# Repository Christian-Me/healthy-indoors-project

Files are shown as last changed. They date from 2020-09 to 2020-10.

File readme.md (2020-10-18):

#  Healthy Indoors project (V0.0.2 ALPHA)

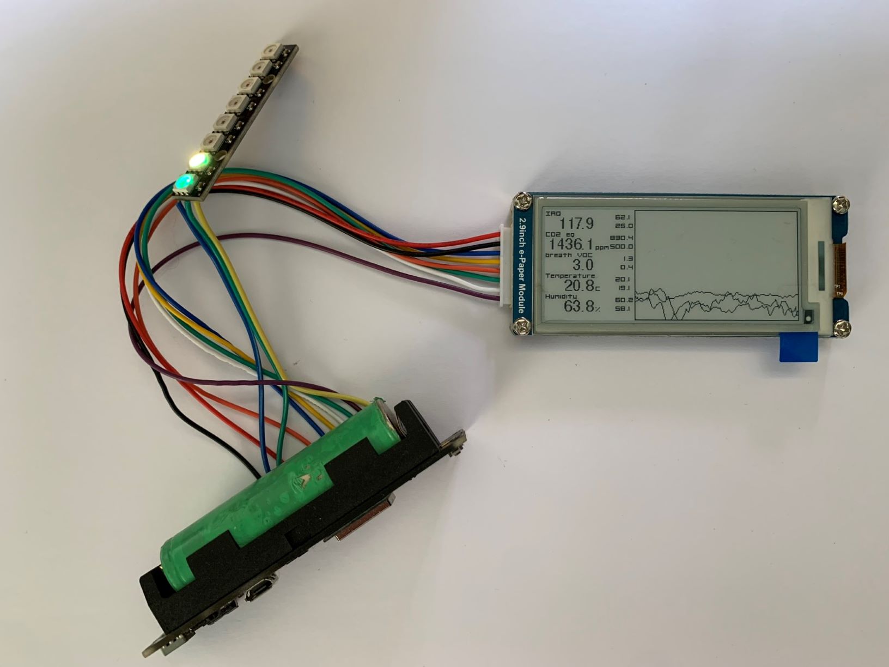
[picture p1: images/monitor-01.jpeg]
monitor node


## version 0.0.2

This version features a TFT monitor node (based on the e-paper version) giving more colorful charts

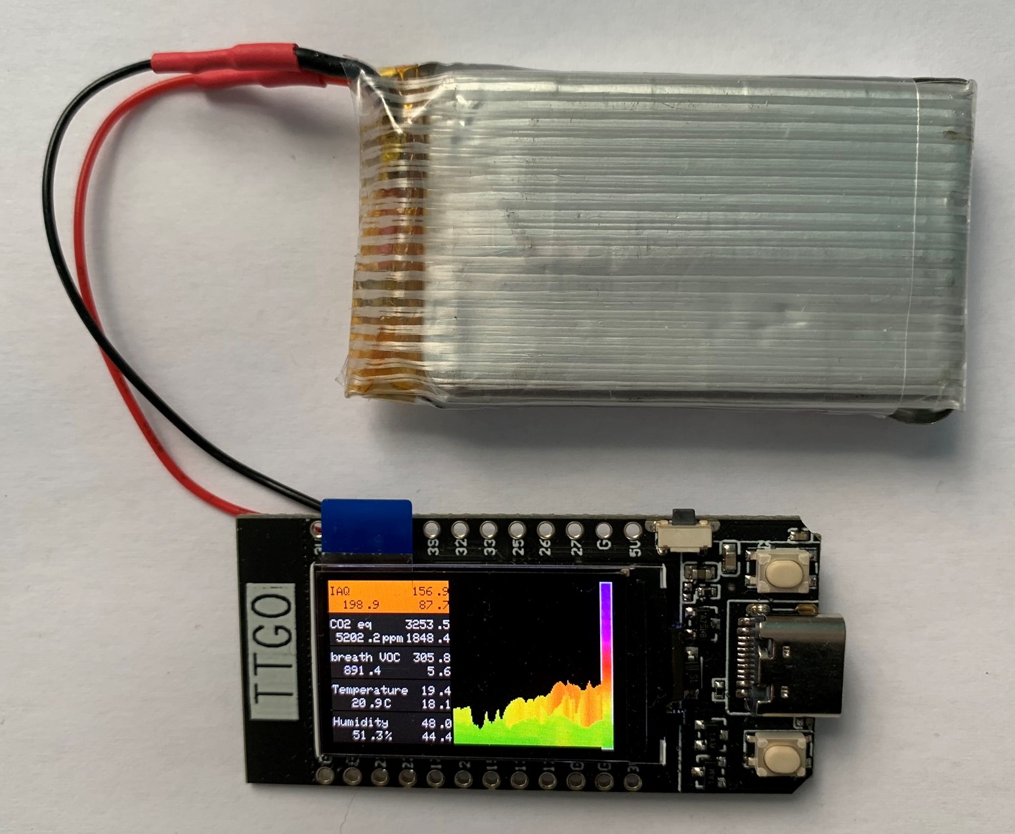
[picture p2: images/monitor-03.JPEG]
monitor node


even if TFT displays are not the best choice for battery powered nodes the small 1.14" TFT is nice (Note: The CO2 figures are CO2 equivalents by the VOC-Sensor - they are not really usable in the current setup)

[Perhaps you like to simulate thermodynamics in real time](./docs/energy2D.md)

open a window

[changes and improvements you find in the changelog](changelog.md)

[first case designs to print with any 3D-Printer](./3d-print/readme.md)

[general information about the software development environment](./docs/software.md)

<!-- START doctoc -->
<!-- END doctoc -->

## introduction

I started this project in September 2020 as a reaction of the global COVID-19 pandemic.

The need of an **as healthy as possible** indoor environment became necessary as it became obvious that [the virus is likely to be able to spread via aerosols](https://www.who.int/news-room/commentaries/detail/transmission-of-sars-cov-2-implications-for-infection-prevention-precautions) which could stay longer in the air and travel further inside rooms as droplets. 

Reading this study by [Risk assessment of aerosols loaded with virus based on CO2-concentration](https://blogs.tu-berlin.de/hri_sars-cov-2/wp-content/uploads/sites/154/2020/08/hartmann_kriegel_2020_en_v3.pdf) and many other publications and working in an open space office environment I was wondering if it is possible to develop indicators for the employees to be aware of the risk and take action. As humans are not good in sensing CO2 levels (or other gas concentrations affecting the air quality) sensors could be a possible way to help.

[Lately I was pointed to this Video](https://youtu.be/u2rNX2T2Hew?t=364). **This made me aware that other factors (humidity, temperature, particles) are important to factor in.** because they effect the *Virus Health (survivability)* and *Immune System health*. It could be important not only to concentrate on CO2 levels as an indicator to reduce the potential concentration COVID-19 (or other) Viruses but also on factors which maybe reduce the survivability of the virus and (perhaps most important) the immune system health of the occupants of a building. We could perhaps raise the risk of an infection if we do too much ventilation(?) and lower the temperature and weaken our immune system?

As we do not have to fit a [square container in a round canister](https://spacecenter.org/apollo-13-infographic-how-did-they-make-that-co2-scrubber/) when CO2 levels are rising. We can simply open the windows. In the beginning of the colder period and higher risk of infections of any kind the question is when, for how long. Second if the air exchange is sufficient. Mid of September Europe is seeing a second wave rising and as the outside temperatures will fall soon the need of an air exchange perhaps must be indicated due to the discomfort of cold air. Noisy street sounds might also prevent people from opening the windows.

Even without the current covid-19 crises the [health risks factors in indoor environments](https://www.euro.who.int/en/health-topics/environment-and-health/air-quality/publications/2015/the-school-environment-policies-and-current-status) should be addressed. Not all offices and nearly no schools have mechanical air ventilation systems (100% fresh air and no air circulation). 

["A new international day to celebrate clean air – and a sustainable recovery from COVID-19"](https://www.euro.who.int/en/health-topics/environment-and-health/air-quality/news/news/2020/9/a-new-international-day-to-celebrate-clean-air-and-a-sustainable-recove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)

## disclaimer

This project do not claim to prevent anybody form dangerous diseases or other harm. Stay distant, wear masks, perform any possible hygiene measures, think about possible ways to avoid long stays indoors, like work from home, remote schooling.

concept diagram

## the Idea

- develop a sensor network to detect accumulation of CO2 or other indicators like Humidity, Tempearture and Particle Concentration
- use multiple sensors to survey larger rooms, find "dead spots"
- Survey the effects of mechanical ventilation, air filters and other methods to improve air quality
- make the project open source that
   - others can participate
   - others can contribute
   - share data and experiences
- raise the awareness of risks in indoor environments
- learn how to improve the air quality and lower the risks with different methods
- test if "self-measured" values can help in communication air quality and perhaps behavior change

## the audience

- everybody who have to stay, study or work in indoor environments
- students who like to build sensor networks, code, analyse the data and perform experiments
- educators who like to teach various aspects form thermo dynamics, electronics, computer science, design, architecture, HVAC systems ... 
- students to get experiences in working on a project remotely using digital techniques like github to exchange ideas and knowlage across borders
- architects and engineers to design environments with better air quality in mind

## the project components

Nothing in this project is really new or innovative. Perhaps the local network idea is a little bit unusual as it does not need an access point as WiFi does. The goal is to establish an ad-hoc network with no setup. Simply place nodes in a room. All nodes in reach can talk to each other and exchange measurements. 

- **sensor nodes** sending environmental sensor readings onto the network
- **monitor nodes** Displaying sensor data on siple (RGB) LEDs, LED arrays, LCD, TFT or e-paper Displays. Monitor nodes can include sensors too.
- **bridge nodes** connecting the local sensor network to other networks like WiFi

### the micro-controller

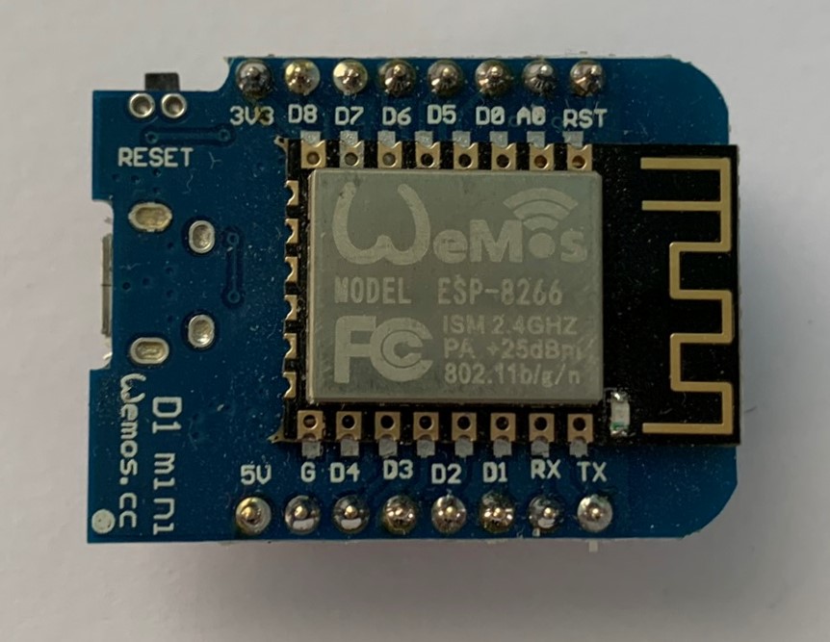
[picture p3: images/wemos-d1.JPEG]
wemos-d1


To start the ESP8266 (or ESP32) is used as it is a cheap and powerful micro-controller with 2.4GHz wireless transceiver build in. Other micro-controllers like Arduino (Atmel) or STM32 are possible but will need additional components for RF-Transmissions

### the network

Several networks and protocols can be used:

- **[esp-now](https://www.espressif.com/en/products/software/esp-now/overview)**: Access point / router free peer to peer ad-hoc network protocol for ESP8266/32 without additional components necessary (default protocol for this project)
- **NRF24L01**: 2.4GHz transceiver modules
- **[LoRa-Wan](https://de.wikipedia.org/wiki/Long_Range_Wide_Area_Network#Klasse_A)**: Long Range Wide Area Network - need of a gateway (public gateways are available). The monitor node can take the role of a gateway and create a local wireless network (to be investigated) and act as a bridge node too.
- **Wifi**: access point is necessary. An ESP8266/32 monitor node can take toe role of an software-AP
- **Bluetooth LE**: Simple data broadcasts over BLE should be possible (ESP32 only)

As esp-now runs natively on ESP8266 or ESP32 it seams like the ideal network protocol to start. The bridge node can connect esp-now to wifi or other networks and protocols

### sensor node

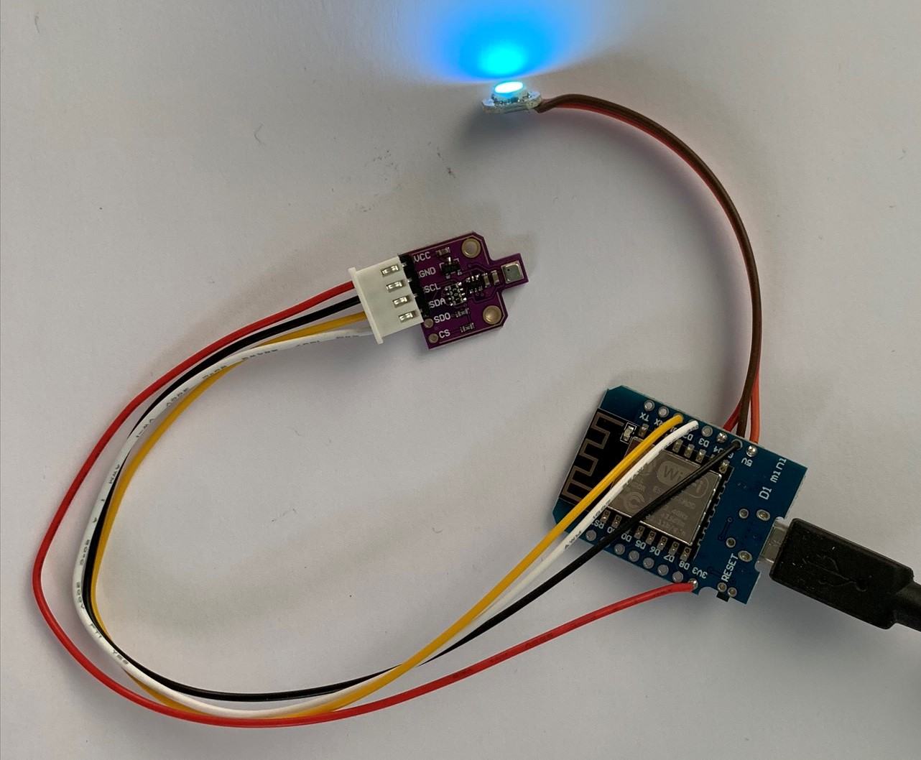
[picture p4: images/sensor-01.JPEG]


The simplest sensor node reads a connected gas sensor and broadcast its readings onto the network.

A Sensor node can also includes a monitor function to display its own sensor reading or if in a broadcast configuration readings of the other sensors too.

some interesting gas sensors (CO2 and VOC)

- **BME680** is an sensor by [Bosch Sensortec](https://www.bosch-sensortec.com/products/environmental-sensors/gas-sensors-bme680/) especially for indoor air quality measurements. Instead of measuring CO2 levels it measures volatile organic compounds (VOC). Not only harmful substances like formaldehyde, lacquers and others but also substances exhaled by humans.

  [interesting video about sensing VOC instead of CO2](https://www.youtube.com/watch?time_continue=1831&v=1niOmSsF-tk&feature=emb_logo)

  all tests in the current version of the project are done with three BME680
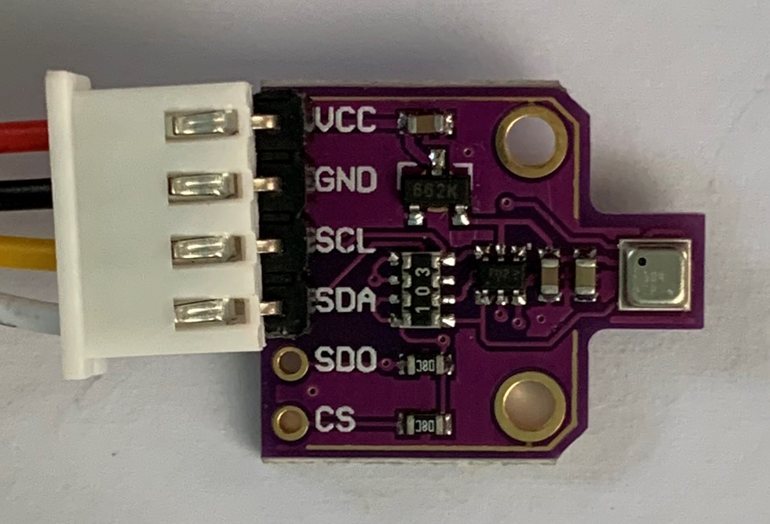
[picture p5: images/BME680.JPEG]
BME680

- **Senseair S8** promising infrared CO2 sensor from [Senseair](https://senseair.com/products/size-counts/s8-residential/) 400 to 2.000 ppm. (currently on delivery)

- **MH-Z19B** Chinese CO2 infrared Sensor from [Winsen-Sensors](https://www.winsen-sensor.com/sensors/co2-sensor/mh-z19b.html) 0 to 2.000 ppm.

- **CCS811** VOC sensor from [Sciosense](https://www.sciosense.com/products/environmental-sensors/ccs811-gas-sensor-solution/) seems interesting for battery operation as the sensor has a mcu integrated for VOC and eCO2 calculations providing a wake from deep sleep signal on programmable threshold alarm. **This sensor does not have a temperature and humidity sensor included! For more precise measurements a BME280, BME680 or similar should be included.**

### monitor nodes

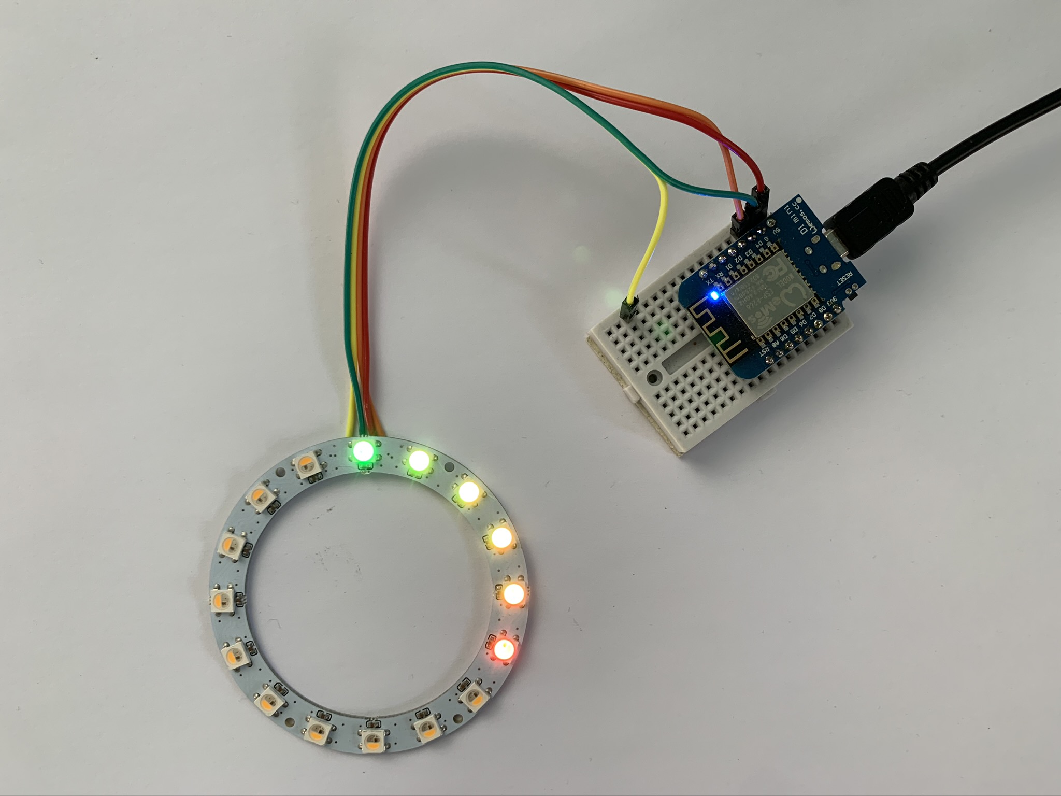
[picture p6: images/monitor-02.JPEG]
rgb-monitor


one or more monitor nodes can join the sensor network to display the air quality. Form a simple LED to RGB led strips, LCD, TFT, OLED or e-paper displays up to an alarm horn.

- A e-paper version is shown on top of the file. e-paper displays are attractive as they are easy to read and keep their contend during deep sleep.

- addressable RGB(W) strips or rings can display the sensor readings in a thermometer or gauge style. A RGB LED can be connected to every sensor node. Addressable RGB chips are preferred as they do not need further components like resistors and keep their state even if the mpu goes into deep sleep to save battery power.

- Small TFT or OLED displays are included in many ESP8266/32 boards. The M5Stack modules come with a TFT display and a attractive case and small LiPo battery

- ESP32 powered user programmable smart watches are available.

- other Monitor solutions can be implemented via bridge nodes

### bridge node

To connect the peer to peer network bridge nodes can join the network. A limitation of esp-now currently is that it does not coexists with WiFi at the same time. Currently that problem is solved by a *esp-now to serial* bridge. It could be solved by switching between esp-now and Wifi with the problem of missing data when switched to the other network.

- *serial2http bridge* The mcu provides a web server for displaying the data on mobile phones or desktop browsers

- *serial2mqtt bridge* (serial2homie) The mcu publishes the sensor data to a MQTT broker. As MQTT does not depend on a special data structure the [homie convention](https://homieiot.github.io/) is used to provide a structure how the sensors announce their services and data.

  Live data of my 3 BME680 are published on **mqtt://broker.hivemq.com:1833** topic: **healthy-indoors-project/#**

- other bridge nodes can be implemented like *serial2thingspeak* or *serial2blynk*

### data analyze

Using a **bridge node** and the mqtt protocoll the sensor data can by analyzed or visualized. The default tool should be [Node-RED](https://nodered.org)

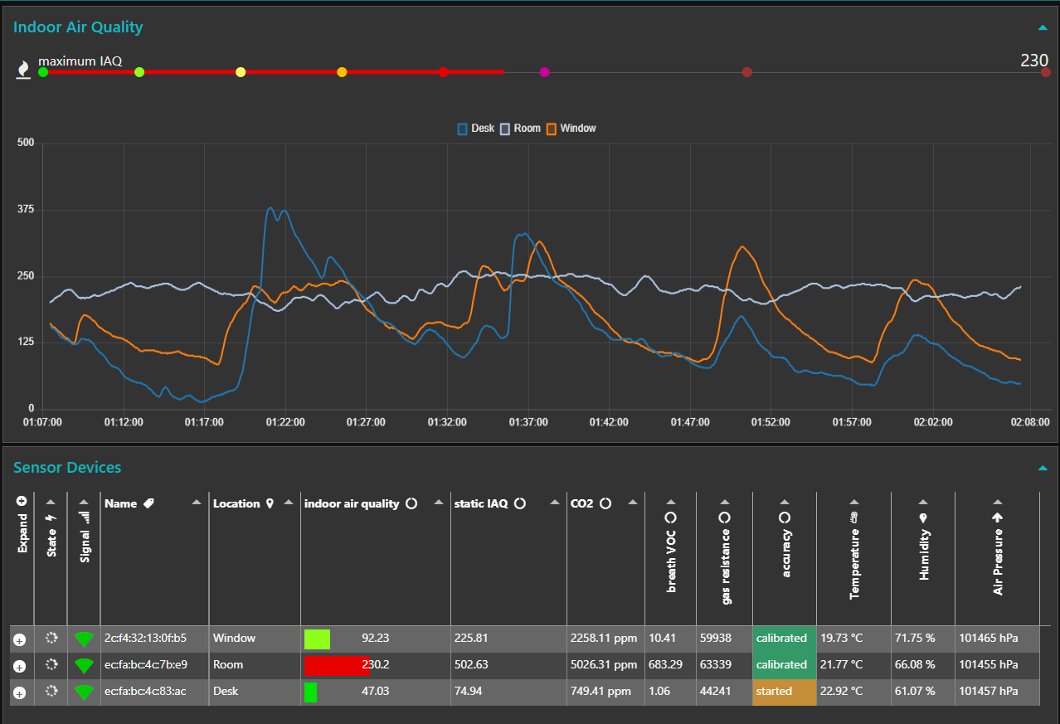
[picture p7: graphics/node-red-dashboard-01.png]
Node-RED dashboard


## project costs

All components are selected with a price point in mind that everybody can participate. Depending where (China or local) you buy the cost can be quite different. Local delivery can be 2-3x higher than orders form China including shipping. (detailed information on components and where to buy could be found in the near future)

- sensor node (8€-25€ BME680)
- monitor node (6€-20€ TFT / 18-30€ e-paper)
- bridge node (4-8€ 2x Wemos D1 mini)

## status of the project

The project is in a **proof of concept** stage. The following questions should be answered to progress:

- is the concept feasible and useful?
- how to interprete the the sensor data?
- how can the project implement in real world environments?
- how to communicate about air quality?

The next steps are

- design and 3D-Print cases for the nodes to take them out into the "real world"
- test nodes in office environments
- test nodes in classrooms
- develop battery powered nodes with suitable battery life
- develop a database solution and data analyze
- detect "window open" state by using window sensors or perhaps the build in temperature readings of most sensors could be used
- address security risks like encryption, authentication
- pairing functionality between nodes for multi room use

## participation and contributions

**The project is seeking for any participation as this is it's main goal!**

- test implementations
- school projects
- scientific advice
- help in any kinds of hardware development. Perhaps producing custom PCBs
- help in software development
- help in addressing security concerns
- any Ideas
- support of any kind
- [...]

## conclusion

As mentioned above this project can only be a small part in fighting against the covid-19 pandemic. Other measures might be more effective but I have a strong believe that there isn't a single solution but many small actions can help flattening the second curve as it is already rolling in.

Feel free to contact me (cmeinert@gmx.net) or use a github issue to enable others to participate.

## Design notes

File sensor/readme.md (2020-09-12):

BME680

Latest Drivers: https://github.com/BoschSensortec/BSEC-Arduino-library

For use with an ESP8266 or ESP32 oyu might have to edit eagle.app.v6.common.ld.h

C:\Users\<username>\.platformio\packages\framework-arduinoespressif8266\tools\sdk\ld

see: https://github.com/BoschSensortec/BSEC-Arduino-library#4-additional-core-specific-modifications

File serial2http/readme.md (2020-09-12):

bridge2http

***************************************
currently NOT working 
any help appreciated
use espnow2serial instead for now
***************************************

receives data form the sensor nodes and makes them accessible via web browser

Based on: https://randomnerdtutorials.com/esp32-esp-now-wi-fi-web-server/
Discussion: https://rntlab.com/question/esp-now-gateway-wifi_mode_sta-with-a-wifi-router/

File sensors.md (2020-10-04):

[BME680 by BOSCH Sensortec](https://www.bosch-sensortec.com/products/environmental-sensors/gas-sensors-bme680/)
[ccs811 by Sciosense](https://www.sciosense.com/products/environmental-sensors/ccs811-gas-sensor-solution/)
[MH-Z19B by Winsen-Sensors](https://www.winsen-sensor.com/sensors/co2-sensor/mh-z19b.html)

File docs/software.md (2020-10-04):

# how to build your own firmware

## project organization 

The project currently knows tree different nodes

- **sensor nodes** containing one or many sensors
- **monitor nodes** nodes to process and display the data
- **bridges** nodes to act as bridges between network protocol and typologies

The functionality of a node is not limited. So for example a monitor node can carry a sensor too or a bridge a display. Even an all in one node is possible. Every node project is a own folder in this project. Ideally it only carries the code necessary for this special node and uses the provided libraries for all the other stuff. 
The build process is controlled by build environments and build flags so functions can be switched on or off by simply commenting or un commenting lines.

## Integrated Development Environment IDE

This project use VSCode together with platform.io as development environment. Instead of using the arduino IDE vs code brings a lot of advantages:

- **One editor for many languages:** The Editor can be used not only for programming micro controller in C/C++ the same environment can be used for Python, JavaScript, PHP, HTML, CSS and many other languages
- **Code Completion** VSCode makes suggestions when you type. This is based not only on dictionaries but also on language structures
- **Linter:** VSCode runs syntax checks and even a compiler in background as you type. So may mistakes or typos are quickly marked before compiling.
- **git and github integration:** Seamless integration of many git and github tools for code versioning & collaboration via github
- **Professional organization:** VSCode brings a professional code organization with standardized file types and structures.
- and many many more features through thousands of extensions.

As a compile / make / build / upload and debug extension platform.io is used. It integrates many hundred of different micro controller, frameworks and boards. This awesome project helps to setup and maintain your build environment together with a in circuit debugger.

Many project like this are using the arduino IDE. This IDE is great as it tricks the newcomer into coding for micro controller in C/C++ by providing a simple to use IDE and simply not telling the user that he is about to learn C/C++. But the Arduino IDE has it's limitations. The code can be interchanged between vscode and Arduino IDE but many adaptations and reorganization has to be done.

The IDE should not be mixed with the framework. A framework organize all the features of different micro controllers in an standard way to do the heavy hardware related lifting. The arduino framework is beside espressive IDF the most popular framework. Many tools and libraries run with the arduiono framework.

## the libraries

The project contains three libraries types providing APIs for certain tasks

- **sensors** these Libraries start with an "s_" like **s_bme680** and interface between the sensor hardware or library and the project
- **communication** these libraries start with "c_" like **c_espnow** interface between the network and the project
- **monitor** these libraries start with "m_" like **m_epaper** to display sensor data

Beside that some other libs exists

- **chart.h** displaying charts on matrix displays
- **color.h** color conversion and calculations
- **ui.h** simple user interface
- **untils.h** misc utilities functions

The following standard libraries are currently used and can be installed by the platform.io library manager (if not automatically installed)

- **Button2** handle button presses, de-bouncing and long- or multiple button presses.
- **GxEPD2** including **Adafruit GFX** and **Adafruit BusIO** to interface with e-paper displays (could perhaps streamlined together with TFT_eSPI)
- **TFT_eSPI** to interface with TFT displays, touch screens and perhaps e-paper displays
- **Adafruit NoPixel** driving addressable RGB and RGBW LEDs

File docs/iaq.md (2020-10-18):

# the Indoor Air Quality index

*need to be revised. These are only data found in the internet*

## introduction

the IAQ is a artificial index defined by the EPA [(United States Environmental Protection Agency)](https://www.epa.gov/indoor-air-quality-iaq). It defines the range from 0-500 in six different categories. The advantage of the IAQ seams to be that many different indices can be mapped into the IAQ Index.

In these project the maximum IAQ is used as an indicator of the Air quality of the room. If necessary the values of different sensors can be weighted to reflect the significance of the sensor type and the relevance of the parameter in the future.

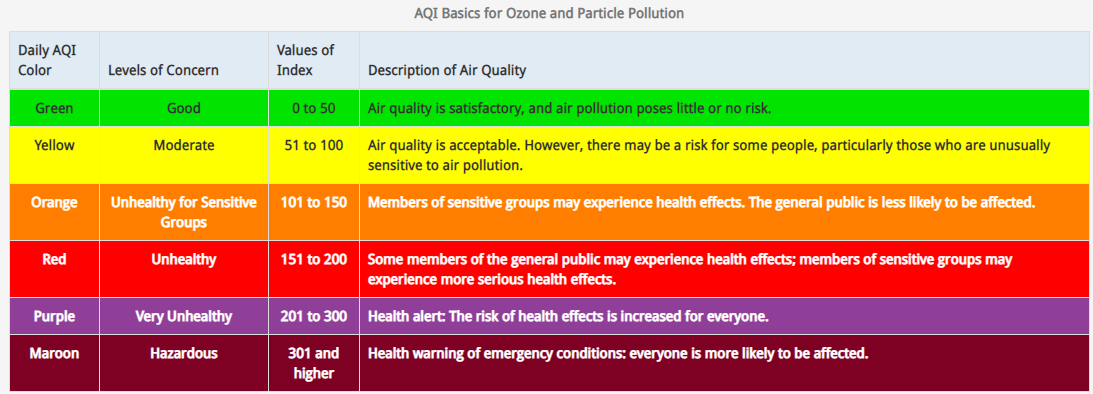
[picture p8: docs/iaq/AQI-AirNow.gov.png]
IAQ overview


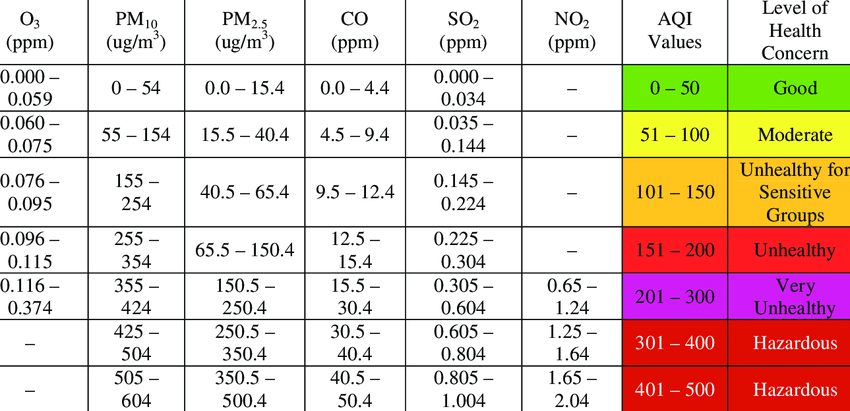
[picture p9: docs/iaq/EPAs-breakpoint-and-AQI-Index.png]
IAQ classification

Classification of values of comprehensive indoor air quality indices of different air pollutants into six different groups (i.e., Good, Moderate, Unhealthy for sensitive groups, Unhealthy, Very unhealthy, and Hazardous) suggested by EPA

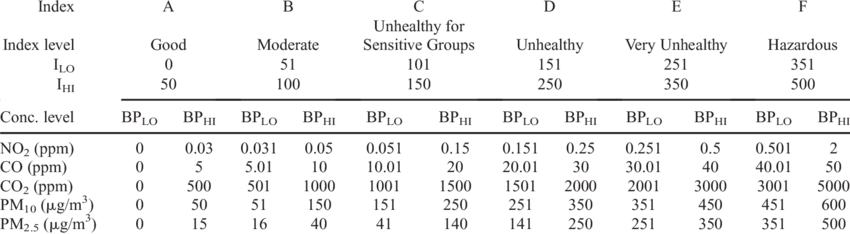
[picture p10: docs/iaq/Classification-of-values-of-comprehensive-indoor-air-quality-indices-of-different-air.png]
IAQ for other parameters


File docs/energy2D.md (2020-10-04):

# simulation of thermodynamics @ home

Energy2D is a simplified 2D thermodynamic simulation tool which is very easy to use. Visualizing the air and temperature flows.

There are certainly flaws in this simplified data models and the parameters iI used but you get a good impression what (probably) happens. You do not need a supercomputer to get real time simulations on your PC. You can play around with the parameters and get instant feedback.

[Energy2D Website and download Windows/Mac/Linux](https://energy.concord.org/energy2d/)

[A jumpstart tutorial on YouTube](https://www.youtube.com/watch?v=M2kSU06829g)

## classroom with tilted window and significant temperature difference 
tilted windows classroom enviornment

## let`s open the windows 
open a window
If you open a window there is a lot of turbulence in the room. The warm air escapes trough the windows but still on the inner wall there is less exchange. If you stop the wind there will be only heat exchange near the window but not a lot of airflow.

## cross ventilation
open a window

If you open a window and the door (open to the outside) the maximum air exchange happens. (but still turbulence in the corners causing a part of the air circulating)

## please note

-  The data model is simplified on a 100x100 grid. (There is a 200x200 version available)
- The particle spreader has no parameters that allow to simulate aerosols or droplets
- the color shows temperatures. The airflow can be visualized by arrows (2nd gif)
- all simulations are done with wind! Without everything is much slower
- java applets are blocked by most browsers. So download the desktop app and create your own models. There are a lot of models available through the examples menu

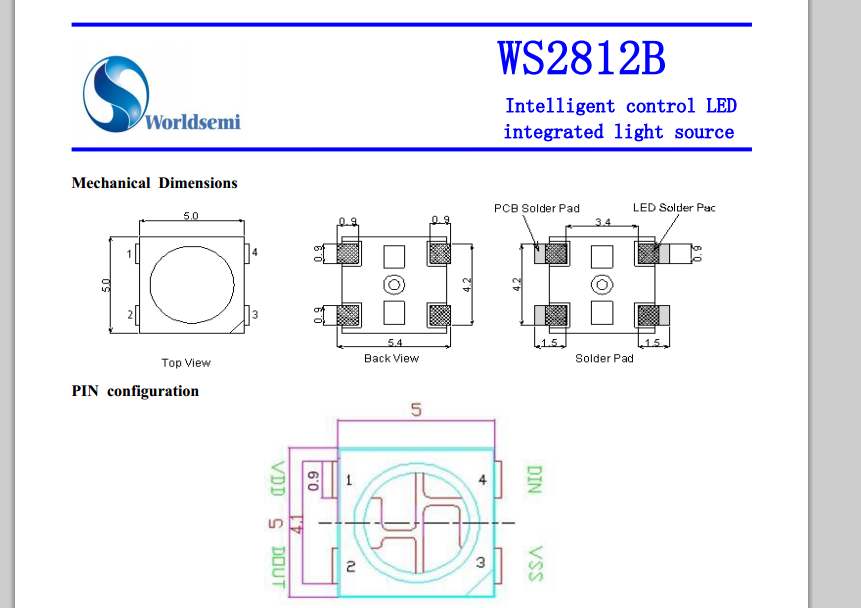
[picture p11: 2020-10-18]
3d-print/components/ws2812b-rgb-led-adafruit-neopixel-1/Renderings/2812b mechanicals.PNG

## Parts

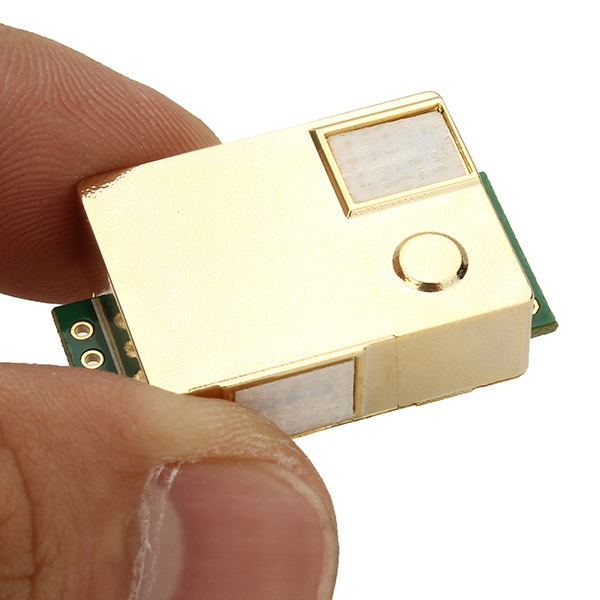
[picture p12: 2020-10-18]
3d-print/components/mh-z19-module-1/mhz19.jpg

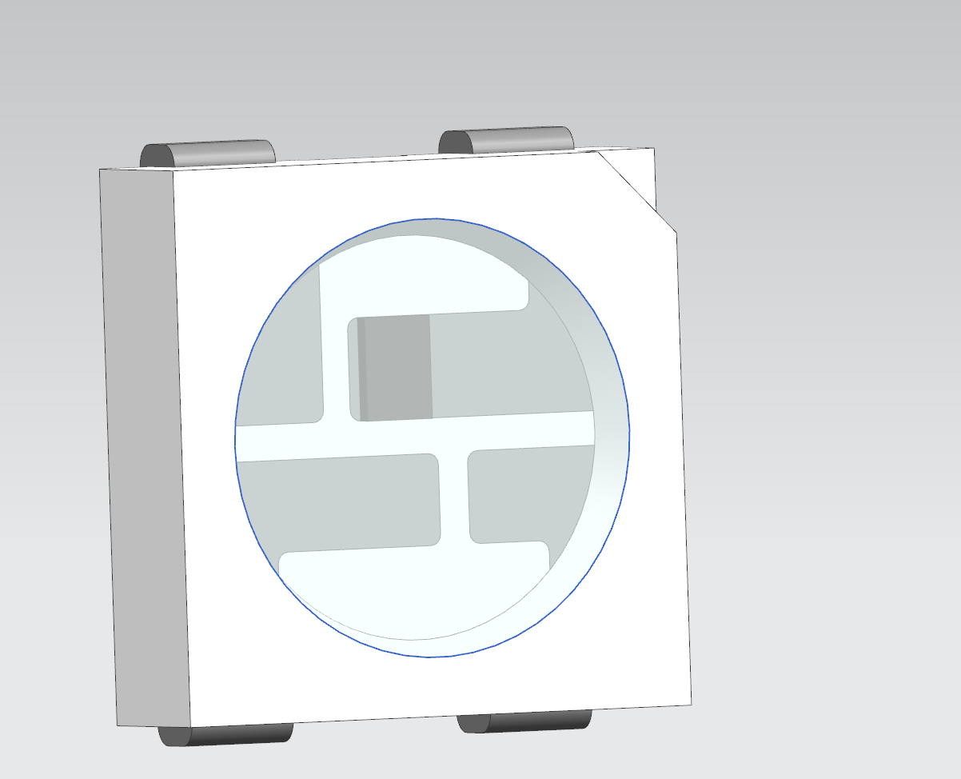
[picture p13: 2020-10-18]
3d-print/components/ws2812b-rgb-led-adafruit-neopixel-1/WS2812_RGB_LED.PNG

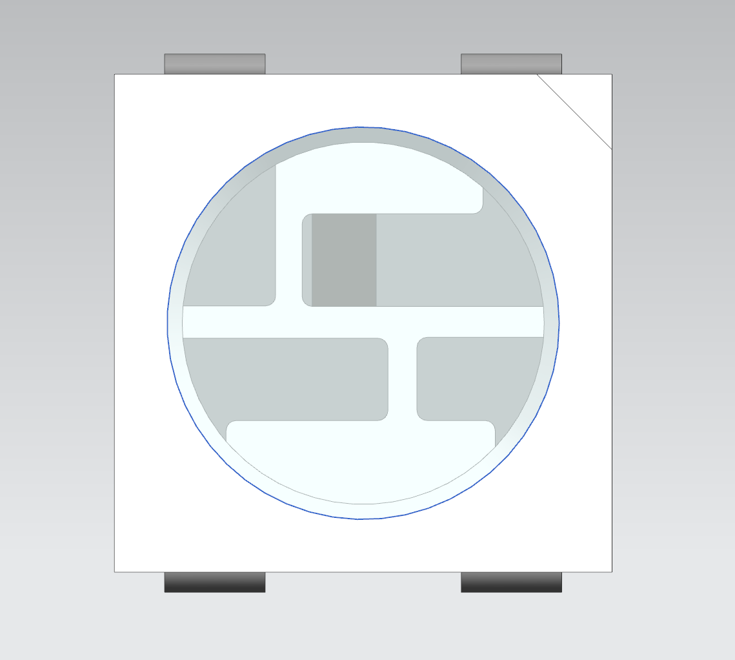
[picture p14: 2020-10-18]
3d-print/components/ws2812b-rgb-led-adafruit-neopixel-1/Renderings/ws2812 view 3.PNG

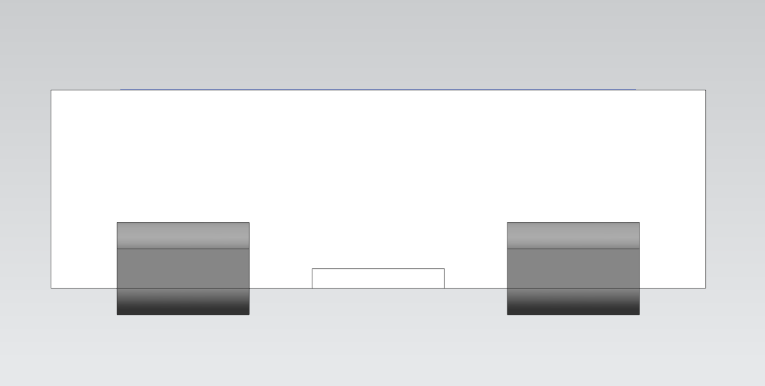
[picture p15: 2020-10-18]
3d-print/components/ws2812b-rgb-led-adafruit-neopixel-1/Renderings/view 4.PNG

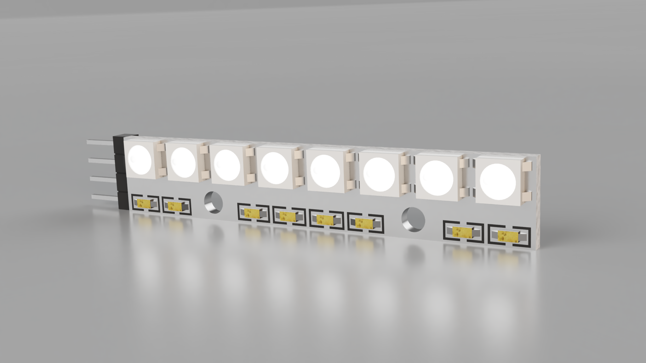
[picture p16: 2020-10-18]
3d-print/components/sw2812b-8/LED WS2812B-8/cfea84ad-056b-4fc8-82c8-7c54f23c799f.PNG

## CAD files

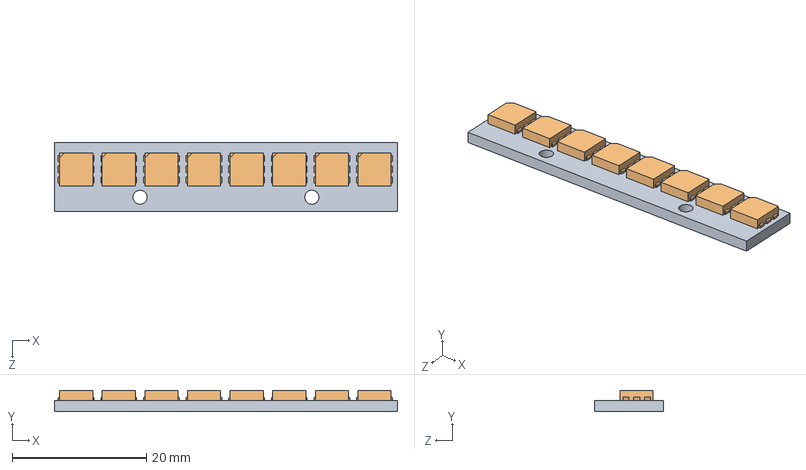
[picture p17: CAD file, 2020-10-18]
3d-print/components/neopixel-stick-8-x-ws2812-5050-rgb-led/NeoPixel Stick - 8 x WS2812 5050 RGB LED.SLDASM
51.1 x 3.19 x 10.2 mm
NeoPixel Stick - 8 x WS2812 5050 RGB LED
LED - SMD RGB (WS2812) x 8

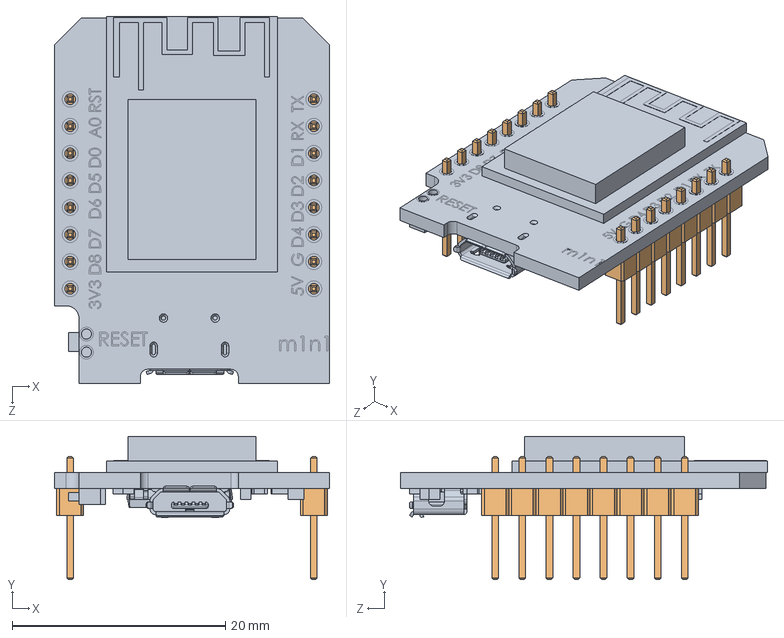
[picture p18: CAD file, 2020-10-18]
3d-print/components/wemos-d1-mini-2.x/Wemos_d1_mini-detailed_assembly.SLDASM
25.8 x 13.4 x 34.4 mm
WEMOS-D1-mini_detailed
Pin_header_str_1x08_p2_54mm x 2

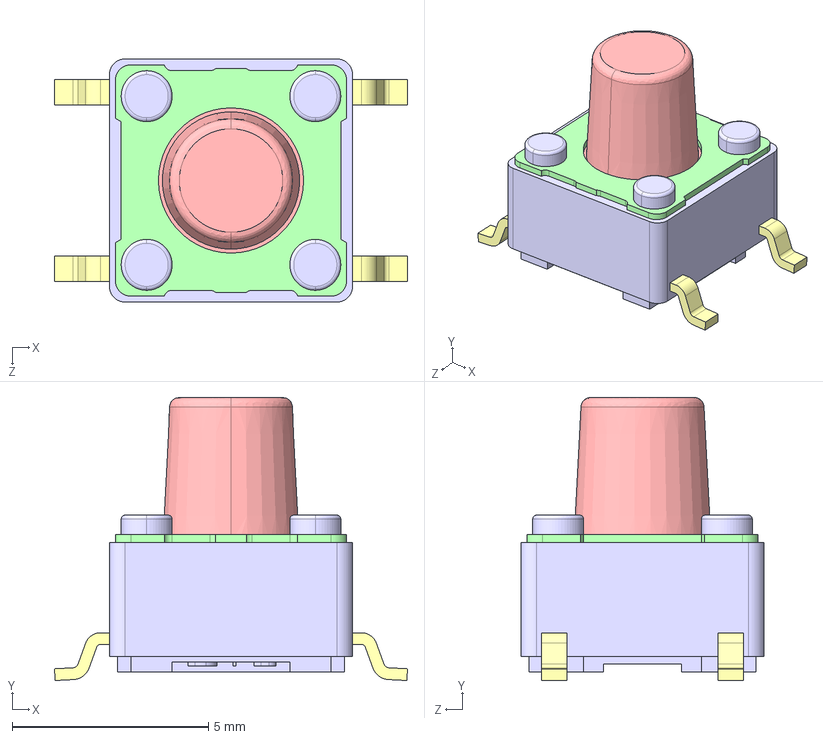
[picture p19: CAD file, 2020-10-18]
3d-print/components/6-2mm-button-switch-1/SWITCH_DTSM-63N-Q-T_DIP.STEP
9.00 x 7.22 x 6.20 mm
SWITCH_DTSM-63N-Q-T_DIP - BASE - pins
SWITCH_DTSM-63N-Q-T_DIP - BASE
SWITCH_DTSM-63N-Q-T_DIP - button
SWITCH_DTSM-63N-Q-T_DIP - sheild
SWITCH_DTSM-63N-Q-T_DIP - shrapnel_ﾄｬﾈﾏｨｨ_

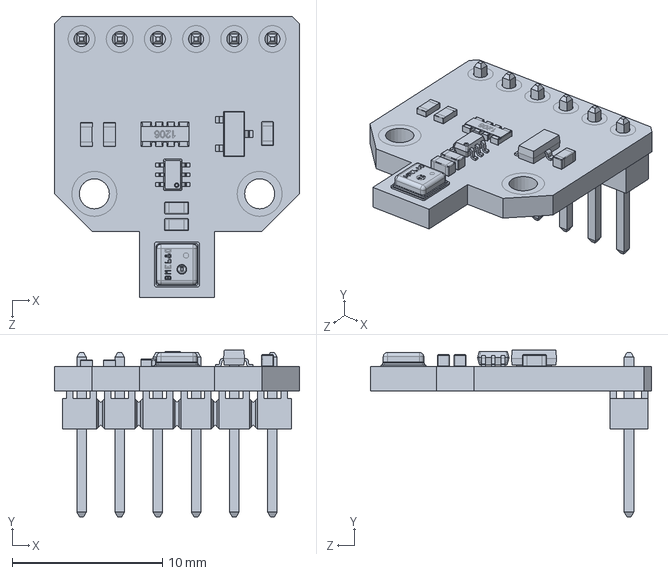
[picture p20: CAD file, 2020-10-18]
3d-print/components/cjmcu-680-bme680-bosch-sensor/CJMCU-680.SLDPRT
16.3 x 11.1 x 18.7 mm

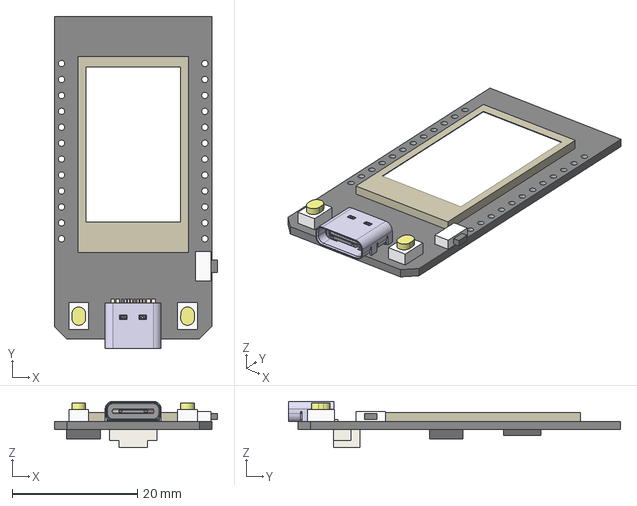
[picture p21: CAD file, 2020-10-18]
3d-print/components/lilygo-ttgo-t-display-esp32/TTGO T-Display.stp
26.0 x 53.0 x 7.40 mm

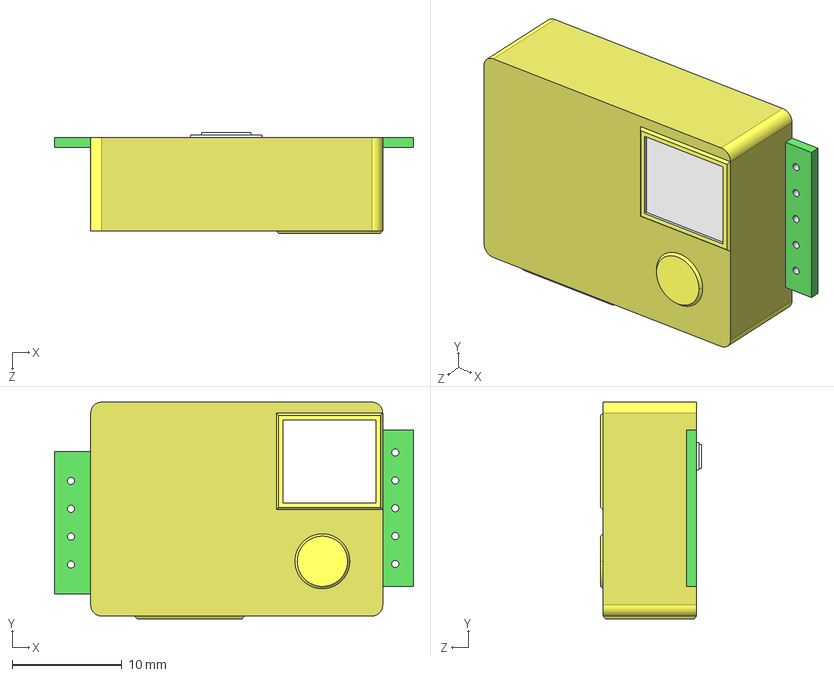
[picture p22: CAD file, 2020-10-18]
3d-print/components/mh-z19-module-1/MH-z19_c02_sens.STEP
32.7 x 19.8 x 9.20 mm

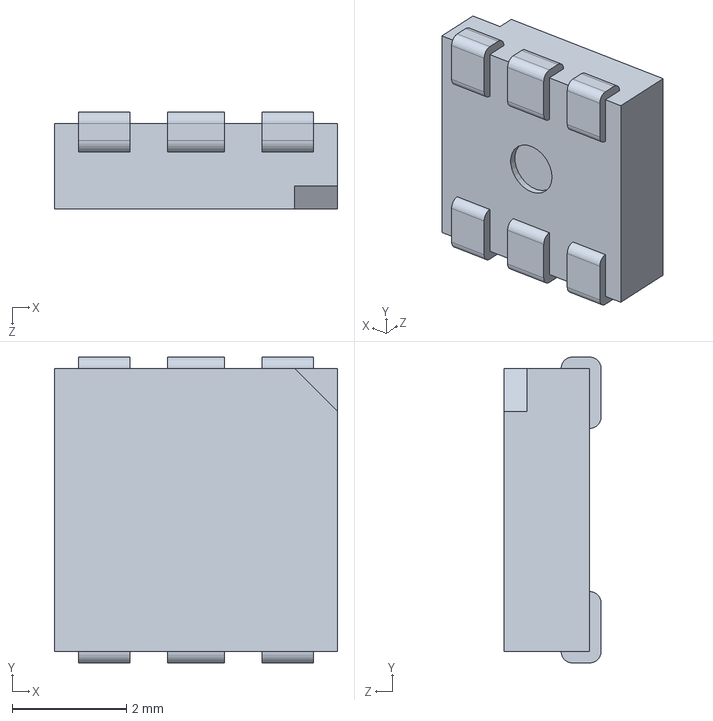
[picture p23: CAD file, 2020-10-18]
3d-print/components/neopixel-stick-8-x-ws2812-5050-rgb-led/LED - SMD RGB (WS2812).sldprt
4.95 x 5.35 x 1.70 mm

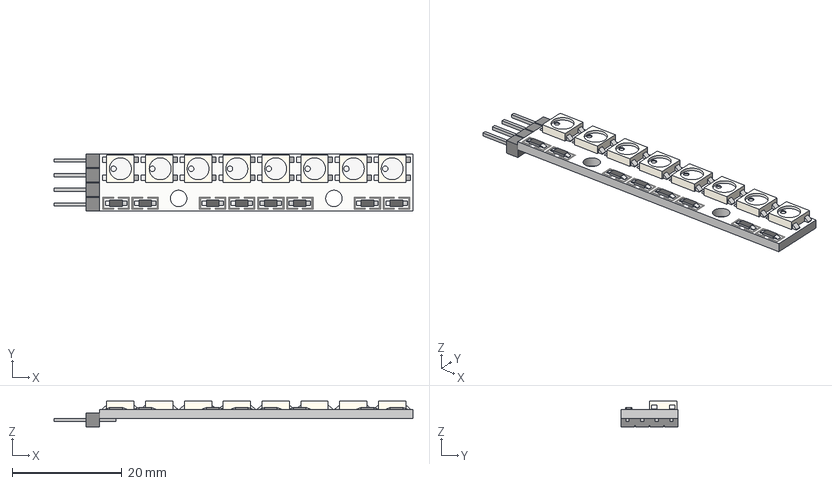
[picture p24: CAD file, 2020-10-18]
3d-print/components/sw2812b-8/LED WS2812B-8/WS2812B-8.step
65.4 x 10.4 x 4.65 mm

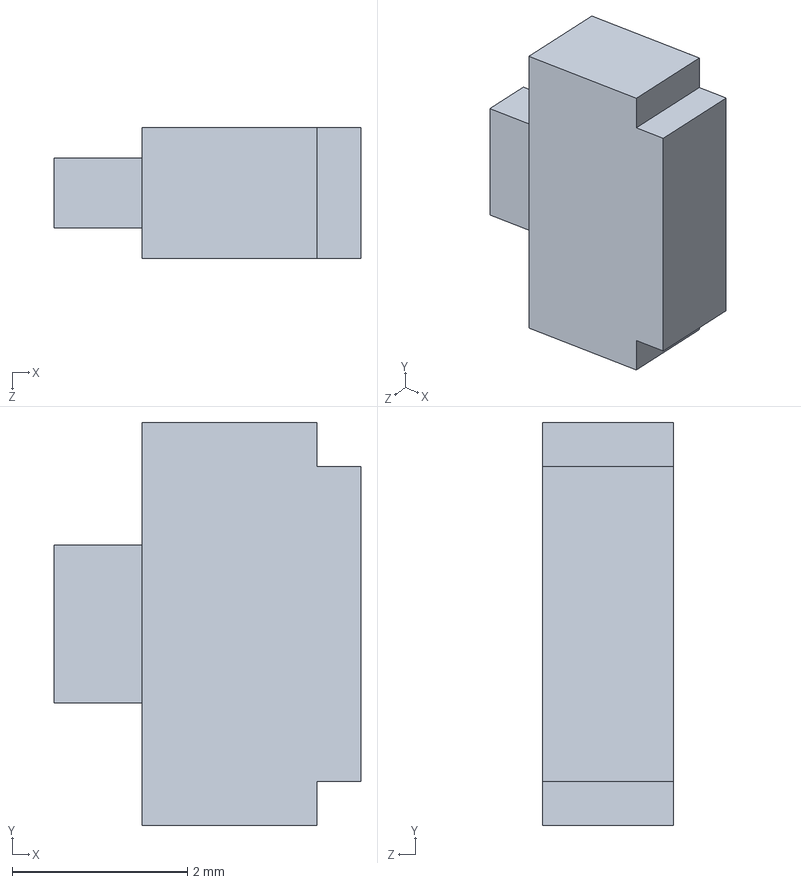
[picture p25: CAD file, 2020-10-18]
3d-print/components/wemos-d1-mini-2.x/push_button.SLDPRT
3.50 x 4.60 x 1.50 mm

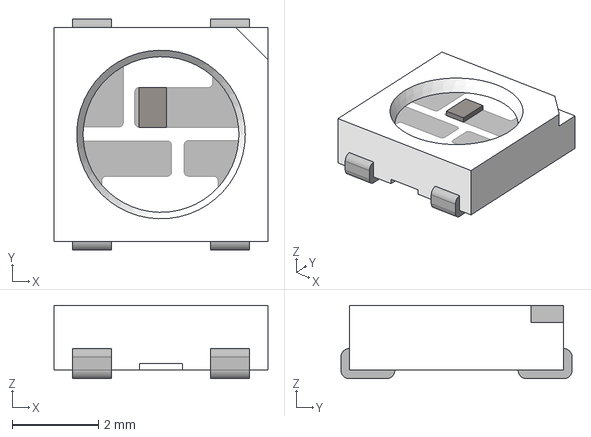
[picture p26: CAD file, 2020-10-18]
3d-print/components/ws2812b-rgb-led-adafruit-neopixel-1/WS2812_RGB_LED_updated.stp
4.95 x 5.35 x 1.70 mm

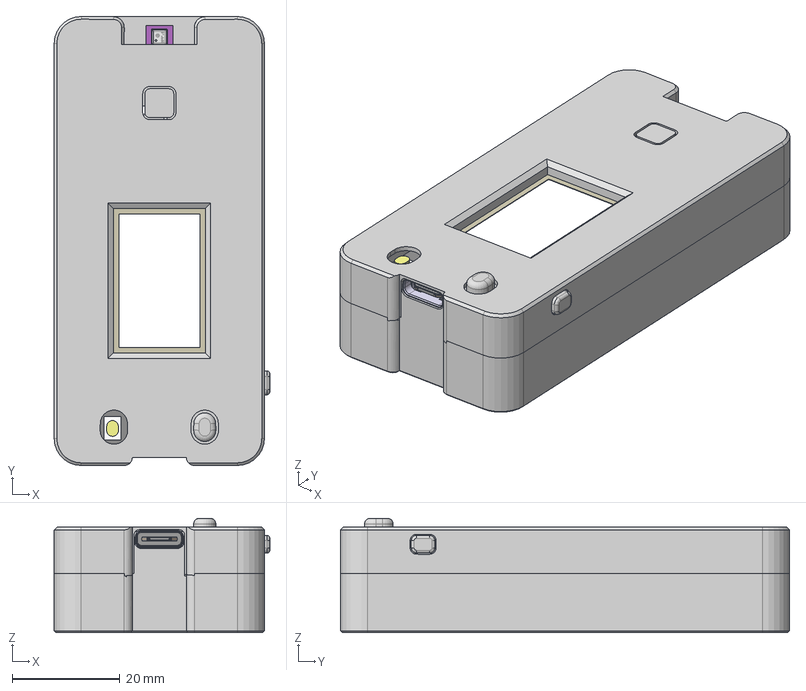
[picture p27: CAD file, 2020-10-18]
3d-print/Monitor TFT.stp
40.0 x 83.3 x 21.2 mm
USB Type C Port (SMD Type)
BME-680
LiPo 1200 10x28x53
WS2812_RGB_LED_PCB
Buttons
MH-Z19
LED Screen
Reset Button

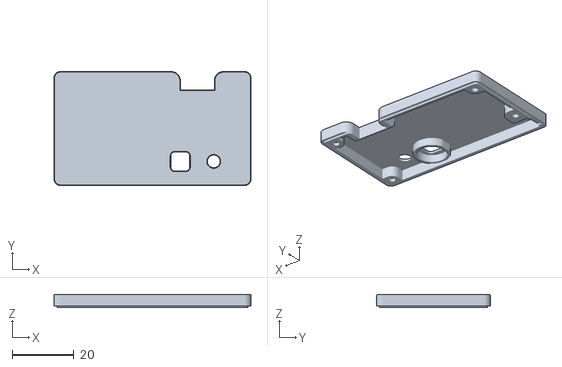
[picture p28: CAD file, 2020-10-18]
3d-print/stl/wemos-2.x-bme680-top.stl
64.0 x 37.0 x 4.30

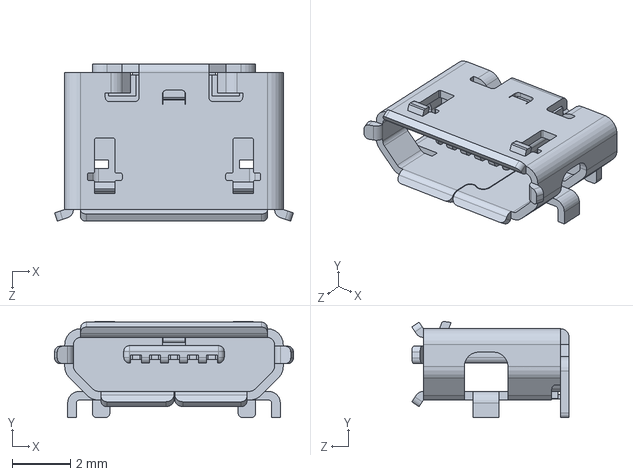
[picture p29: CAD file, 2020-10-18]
3d-print/components/wemos-d1-mini-2.x/usb socket.SLDPRT
8.20 x 3.30 x 5.40 mm

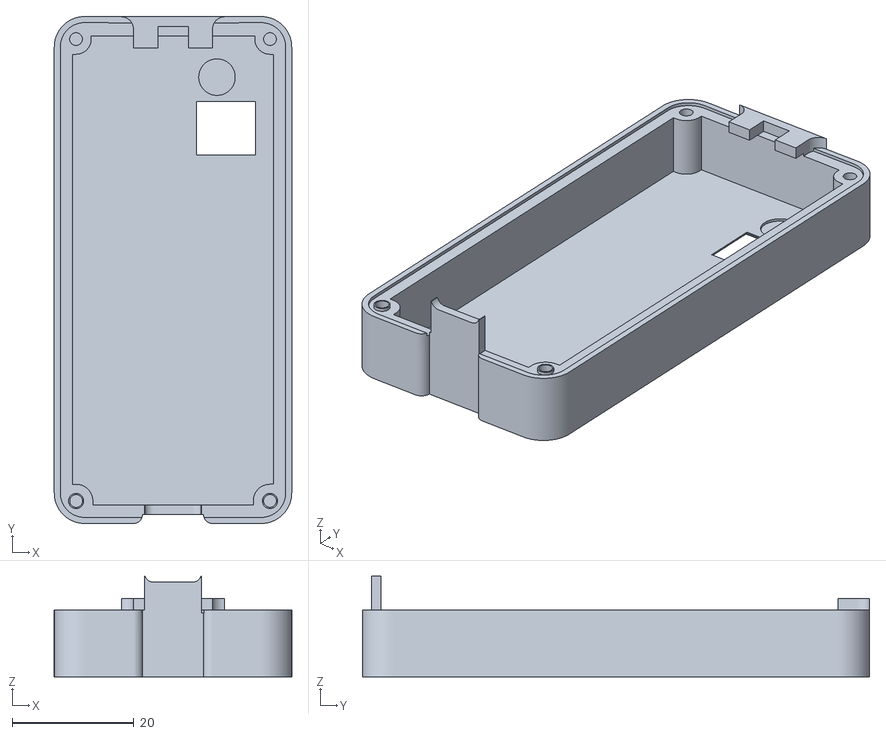
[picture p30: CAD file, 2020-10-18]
3d-print/stl/bottom-mhz19.stl
39.0 x 83.3 x 16.6

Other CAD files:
3d-print/components/wemos-d1-mini-2.x/SOIC_16_ch340.SLDPRT
3d-print/stl/bottom.stl
3d-print/components/wemos-d1-mini-2.x/WEMOS-D1-mini_detailed.SLDPRT
3d-print/stl/wemos-2.x-bme680-bottom.stl
3d-print/components/lilygo-ttgo-t-display-esp32/TTGO T-Display.prt
3d-print/components/mh-z19-module-1/MH-z19_c02_sens.SLDPRT
3d-print/components/mh-z19-module-1/Monitor TFT v8.f3z
3d-print/components/neopixel-stick-8-x-ws2812-5050-rgb-led/NeoPixel Stick - 8 x WS2812 5050 RGB LED.SLDPRT
3d-print/components/wemos-d1-mini-2.x/Pin_header_str_1x08_p2_54mm.sldprt
3d-print/components/wemos-d1-mini-2.x/WEMOS-D1-mini_stl.STL
3d-print/components/ws2812b-rgb-led-adafruit-neopixel-1/WS2812_RGB_LED_Updated.igs
3d-print/components/ws2812b-rgb-led-adafruit-neopixel-1/WS2812b Updated.prt
3d-print/components/ws2812b-rgb-led-adafruit-neopixel-1/WS2812b updated.x_t
3d-print/stl/top.stl
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

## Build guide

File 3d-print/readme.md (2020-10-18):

# case designs for sensor and monitor nodes

## sensor node

simple sensor node with an 

- ESP8266 (WEMOS D1-mini)
- BME680
- RGBW LED,
- reset and user button

the button will be used to change display modes and pairing

Dimensions 6.5 x 3.6 x 1 cm

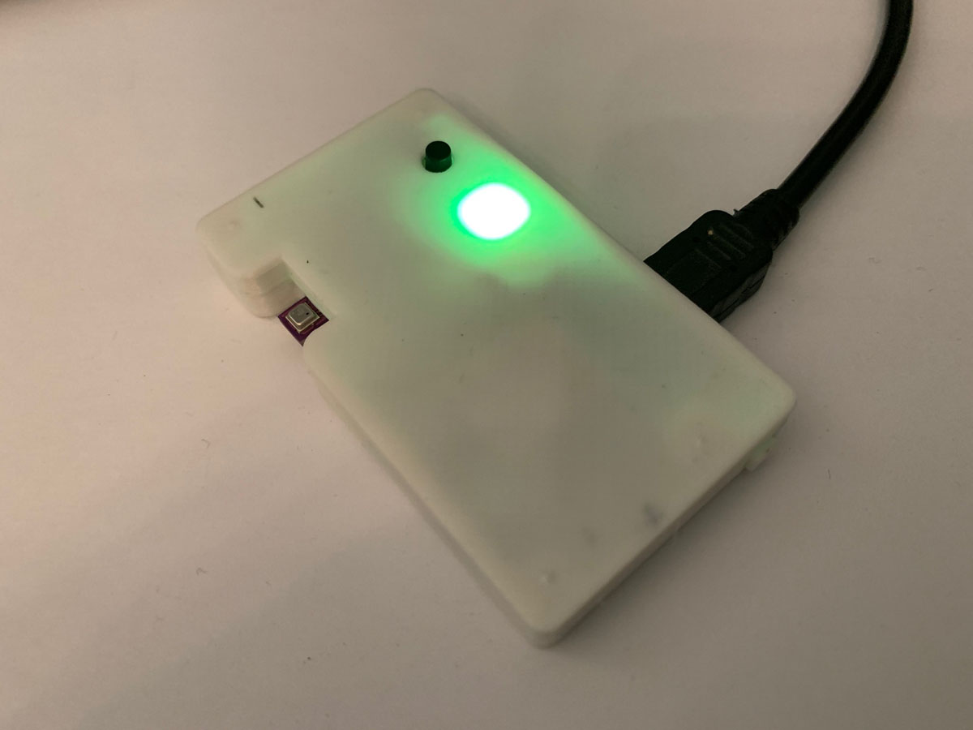
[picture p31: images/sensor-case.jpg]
Sensor Node


The models are available here:

[Fusion 360](https://a360.co/2H2ZKQy)

[Grab CAD](https://grabcad.com/library/healthy-indoors-project-sensor-1)

latest STEP and STL file here on github

## monitor node

monitor node containing

- TTGO T-Display ESP32 with 1.4" TFT
- 1200 mA/h LiPo battery
- BME680 VOC, Temp, Pressure and Humidity Sensor
- MHZ19 CO2 Sensor
- two user buttons
- reset button
- USB-C interface

Dimensions 8.5 x 4 x 2 cm 

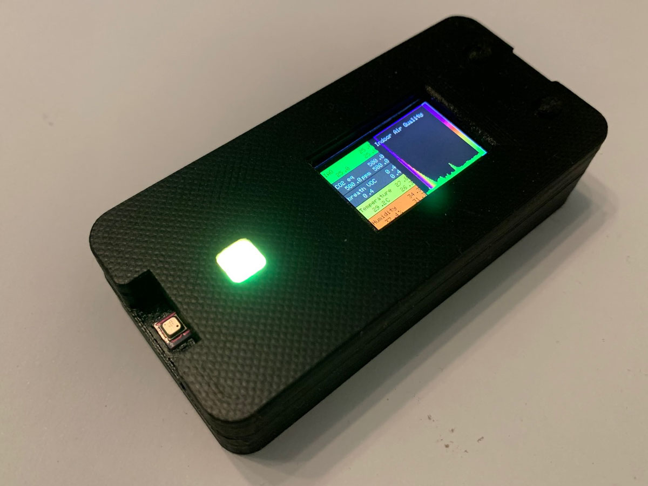
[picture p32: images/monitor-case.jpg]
Monitor Node


[Fusion 360](https://a360.co/2SuLfXz)

[GrabCad](https://grabcad.com/library/healthy-indoors-project-monitor-1)

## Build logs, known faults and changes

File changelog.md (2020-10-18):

# changelog

## version 0.0.2 (alpha)

- many modules are now sharable between different nodes as they are now packed in c++ classes.
- support for color TFT matrix displays including "screen saver" and backlight dimming.
- new color scale to better indicate the IAQ levels (before it was only the complete hue circle)
- additional graphs for temperature and humidity.
- added software.md explaining a little bit how to build the firmware
- case design for combined battery powered ESP32 monitor & sensor node and basic sensor node

## version 0.0.1 (alpha)

- initial release

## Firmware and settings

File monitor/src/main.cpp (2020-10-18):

#define MODULE_NAME "espnow2monitor"
#include <Arduino.h>
#include "../../include/datatypes.h"
#include "utils.h"
#ifdef ESP32 // nicer LOG output for ESP32
#include "esp32-hal-log.h"
#endif

// struct_message incomingReadings;
dataPacket packet;

// data collection and storage
#include "datacollection.h"
dataCollection dataStorage; // don't change this name because it is directly referenced by other classes (ToDo: fix this;)

// communication plugin
#ifdef COMUNICATION_ESPNOW
  #include "c_espnow.h"
  c_espnow comm1;
#endif

// sensor node specific libraries

#define USE_BME680
//#define USE_CCS811
#define USE_MHZ19

#ifdef USE_BME680
  #include "s_bme680.h"
  s_bme680 bme680;
#endif
#ifdef USE_CCS811
  #include "s_ccs811.h"
  s_ccs811 ccs811;
#endif
#ifdef USE_MHZ19
  #include "s_mhz19.h"
  s_mhz19 mhz19;
#endif

// monitor node specific libraries
#ifdef MONITOR_NEOPIXEL
  #include "m_neopixel.h"
  m_neopixel neopixel;
#endif
#ifdef MONITOR_EPAPER
  #define MATRIX_DISPLAY
  #include "epaperDisplay.h"
  epaperDisplay matrixDisplay;
  #include "chart.h"
  #include "ui.h"
#endif
#ifdef MONITOR_TFT
  #define MATRIX_DISPLAY
  #include "tftDisplay.h"
  tftDisplay matrixDisplay;
  #include "chart.h"
  chart iaqChart;
  chart humidityChart;
  chart temperatureChart;
  chart co2Chart;
  uint8_t currentChart = 0;
  #include "ui.h"
  ui mainUi;
#endif


void updateUI(void) {
  iaqChart.addSample("iaq");
  humidityChart.addSample("humidity");
  temperatureChart.addSample("temperature");
  co2Chart.addSample("co2");
}

// handle incoming data

void dataReceived() {
  digitalWrite(LED_BUILTIN, LOW);
  dataStorage.update((char *)WiFi.macAddress().c_str(), &packet);

  updateUI();

  digitalWrite(LED_BUILTIN, HIGH);
}

void dataReceived(const uint8_t *mac_addr, const uint8_t *data, int dataLength) {

  digitalWrite(LED_BUILTIN, LOW);

  char macStr[18];
  snprintf(macStr, sizeof(macStr), "%02x:%02x:%02x:%02x:%02x:%02x",
           mac_addr[0], mac_addr[1], mac_addr[2], mac_addr[3], mac_addr[4], mac_addr[5]);
  size_t length = dataLength;
  if (sizeof(packet)<length) length=sizeof(packet); // limit length to maximum length of package if received package is bigger than the data structure of this node.
  initDataPacket(&packet); // fill packet with defaults (necessary is incoming packit is smaller than received package)
  memcpy(&packet, data, length);

  dataStorage.update(macStr, &packet);

  updateUI();

  digitalWrite(LED_BUILTIN, HIGH);
}

void button1Handler(uint8_t button, uint8_t event) {
  comm1.pauseReceive();
  if (matrixDisplay.getBacklight()==0) {
    matrixDisplay.setBacklight(BACKLIGHT_BRIGHTNESS);
    matrixDisplay.resetScreensaver();
  } else {
    currentChart++;
    if (currentChart>3) currentChart=0;
    switch (currentChart) {
      case 0: // IAQ
        Serial.println(F("Show IAQ chart"));
        iaqChart.visible(true);
        humidityChart.visible(false);
        temperatureChart.visible(false);
        co2Chart.visible(false);
        break;
      case 1: // Humidity
        Serial.println(F("Show Humidity chart"));
        iaqChart.visible(false);
        humidityChart.visible(true);
        temperatureChart.visible(false);
        co2Chart.visible(false);
        break;
      case 2: // Temperature
        Serial.println(F("Show Temperature chart"));
        iaqChart.visible(false);
        humidityChart.visible(false);
        temperatureChart.visible(true);
        co2Chart.visible(false);
        break;
      case 3: // CO2
        Serial.println(F("Show CO2 chart"));
        iaqChart.visible(false);
        humidityChart.visible(false);
        temperatureChart.visible(false);
        co2Chart.visible(true);
        break;
    }
    // comm1.resumeReceive();
  }
}

void setup() {
  pinMode(LED_BUILTIN, OUTPUT);
  Serial.begin(115200);     // initialize serial port

  Serial.println();
  Serial.println(F("-----------------------------------------------"));
  Serial.println(F("Healthy indoor project"));
  Serial.println(F("Node: Monitor"));
  #ifdef MONITOR_NEOPIXEL
    Serial.println(F("Display: neopixel"));
  #endif
  #ifdef MONITOR_EPAPER
    Serial.println(F("Display: epaper"));
  #endif
  #ifdef MONITOR_TFT
    Serial.println(F("Display: TFT"));
  #endif
  Serial.println(F("Version 0.0.1"));
  Serial.println(F("-----------------------------------------------"));
  Serial.println();
  dataStorage.init();

  // init sensor nodes
  #ifdef USE_BME680
    bme680.init();
  #endif
  #ifdef USE_CCS811
    ccs811.init();
  #endif
  #ifdef USE_MHZ19
    mhz19.init();
  #endif

  #ifdef MATRIX_DISPLAY // init matrix display first for splash screen
    matrixDisplay.init();
    matrixDisplay.registerButtonCallback(&button1Handler);
    mainUi.splash();
    unsigned long timer = millis() + 2000;
    while (timer>millis()) {
      matrixDisplay.loop(); // let the display do it`s thing as log as we wait
    }
    display.fillScreen(TFT_BLACK);
  #endif

  #ifdef MONITOR_NEOPIXEL // using neopixel and setting the brightness value
    neopixel.init(27, "iaq", 1, NEO_RGBW, 50);
  #endif

  #ifdef MATRIX_DISPLAY // init chart & ui for matrix dispaly
    iaqChart.init(F("Indoor Air Quality"),true, 20, 104,0,display.width()-104,display.height(),0,500,&getIAQColor,nullptr,&getIAQAlarm, &drawColorBar);
    humidityChart.init(F("Humidity"), false, 20, 104,0,display.width()-104,display.height(),0,100,&getHumidityColor,nullptr,&getHumidityAlarm, &drawColorLine);
    temperatureChart.init(F("Temperature"),false, 20, 104,0,display.width()-104,display.height(),0,45,&getTemperatureColor,nullptr,&getTemperatureAlarm, &drawColorLine);
    co2Chart.init(F("CO2"),false, 20, 104,0,display.width()-104,display.height(),0,4000,&getCO2Color,nullptr,&getCO2Alarm, &drawColorLine);
    mainUi.init();
  #endif

  #ifdef COMUNICATION_ESPNOW // using esp-now
    // 1. register callback for receiveing data
    comm1.registerReceiveCallback(&dataReceived);
    // 2. initialize espnow
    comm1.init("espnow2epaper");
  #endif
  Serial.println(F("Done."));
  Serial.println();

}

void loop() {
  #ifdef COMUNICATION_ESPNOW  // communicator loop
    comm1.loop();
  #endif
  #ifdef MONITOR_NEOPIXEL // neopixel loop
    neopixel.loop();
  #endif
  #ifdef MONITOR_EPAPER // epaper loop
    matrixDisplay.loop();
    mainUi.loop();    // refresh ui
    iaqChart.loop(); // refresh chart
    humidityChart.loop(); // refresh chart
    temperatureChart.loop(); // refresh chart
  #endif
  #ifdef MATRIX_DISPLAY // matrix display loop
    matrixDisplay.loop();
    mainUi.loop();    // refresh ui
    iaqChart.loop(); // refresh chart
    humidityChart.loop(); // refresh chart
    temperatureChart.loop(); // refresh chart
  #endif
  #ifdef USE_BME680
    if (bme680.read(&packet)) {
      comm1.send(&packet);
      dataReceived(); // write to data collection and update charts
    }
  #endif
  #ifdef USE_CCS811
    if (ccs811.read(&packet)) {
      comm1.send(&packet);
      dataReceived();
    }
  #endif
  #ifdef USE_MHZ19
    if (mhz19.read(&packet)) {
      comm1.send(&packet);
      dataReceived();
    }
  #endif
}

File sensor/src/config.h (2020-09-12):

/**************************************************************************
 * Neopixel
 **************************************************************************/

#define NEOPIXEL_PIN D4
#define LED_AMOUNT 1
#define LED_TYPE NEO_RGBW
//   NEO_KHZ800  800 KHz bitstream (most NeoPixel products w/WS2812 LEDs)
//   NEO_KHZ400  400 KHz (classic 'v1' (not v2) FLORA pixels, WS2811 drivers)
//   NEO_GRB     Pixels are wired for GRB bitstream (most NeoPixel products)
//   NEO_RGB     Pixels are wired for RGB bitstream (v1 FLORA pixels, not v2)
//   NEO_RGBW    Pixels are wired for RGBW bitstream (NeoPixel RGBW products)

// IMPORTANT: To reduce NeoPixel burnout risk, add 1000 uF capacitor across
// pixel power leads, add 300 - 500 Ohm resistor on first pixel's data input
// and minimize distance between Arduino and first pixel.  Avoid connecting
// on a live circuit...if you must, connect GND first.

#define NEOPIXEL_MIN_BRIGHTNESS 50          // min brightness of color indicator
#define NEOPIXEL_MAX_BRIGHTNESS 150         // max brightness of color indicator
#define NEOPIXEL_INDICATOR_BRIGHTNESS 150   // brightness of sensor indicator
#define NEOPIXEL_REFRESH 2000               // refresh rate;
#define NEOPIXEL_MAX_SAMPLED_DEVICES 5      // maximum device to sample
#define NEOPIXEL_INDICATOR_FADE_STEP 1      // step to fade each loop 
#define NEOPIXEL_INDICATOR_FADE_WAIT 10     // step to fade each loop
#define NEOPIXEL_SINGLE_LED_VALUE 1         // for singe LED show 1=max, 2=average, 3=min

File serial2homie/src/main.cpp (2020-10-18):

/*
  Healthy Indoors Project

  serial 2 homie (MQTT)

  DESCRIPTION:
  the data from the esp-now local network received via the espnow2serial node is decoded and 
  published to an mqtt broker following the homie convention

  LIMITATIONS:
   - only unencrypted communication is tested
   
  IMPROVEMENTS
   - establish TLS encrypted communication
   - the serial in decoder should be looked over by an expert ;)

  This project was started September 2020 by Christian Meinert
  as a reaction of the global COVID-19 epidemic and the need of an as healthy as possible indoor enviornment
  as it became obvious that the virus is likely to be able to spread via aerosols which could stay longer
  in the air and travel further inside rooms as droplets.

  original project location on Github :

  Stay healthy, keep distance, open windows!
*/
#define VERSION "0.0.1"

#ifdef ESP32
  #include <WiFi.h>
#else
  #include <ESP8266WiFi.h>
#endif
#include "../../include/datatypes.h"
#include <SoftwareSerial.h>
#include <CRC32.h>

// edit all your credentials here:
#include "../../include/credentials.h"

// client to handle outbound traffic
#include <homieclient.h>
homieClient server; // create a instance of your server

CRC32 crc;
uint32_t checksum;

#if defined(ESP8266) && !defined(D5)
#define D5 (14)
#define D6 (12)
#define D7 (13)
#define D8 (15)
#endif

#ifdef ESP32
#define BAUD_RATE 57600
#else
#define BAUD_RATE 57600
#endif

SoftwareSerial serialPort;
#define SERIAL_BUFFER_MAX 128


// struct_message incomingReadings;
dataPacket packet;
unsigned char serialBuffer[SERIAL_BUFFER_MAX]; //buffer to hold incoming packet,

void OnDataRecv(const uint8_t * mac_addr, const uint8_t *incomingData, int len) {
  if (!server.rts()) return;
  digitalWrite(LED_BUILTIN, LOW);
  // Copies the sender mac address to a string
  char macStr[18];
  snprintf(macStr, sizeof(macStr), "%02x:%02x:%02x:%02x:%02x:%02x",
           mac_addr[0], mac_addr[1], mac_addr[2], mac_addr[3], mac_addr[4], mac_addr[5]);
  if (len>(int) sizeof(packet)) len = sizeof(packet);
  memcpy(&packet, incomingData, len);

#ifdef SERIAL_DEBUG  
  Serial.printf(" Packet length       : %d/%lu bytes\n", len, sizeof(packet));
  Serial.printf(" Board ID            : %s \n", macStr);
  Serial.printf(" Uptime              : %lu \n", packet.uptime);
  Serial.printf(" Sensor ID           : %d \n", packet.sensorType);
  Serial.printf(" Sensor Type         : %s \n", sensors[packet.sensorType]);
  Serial.printf(" Sensor accuracy     : %d \n", packet.accuracy);
  Serial.printf(" temperature         : %4.2f C\n", packet.temperature);
  Serial.printf(" humidity            : %4.2f %%\n", packet.humidity);
  Serial.printf(" pressure            : %.0f hPa\n", packet.pressure);
  Serial.printf(" gasResistance       : %.0f Ohm\n", packet.gasResistance);
  Serial.printf(" iaq                 : %.2f \n", packet.iaq);
  Serial.printf(" staticIaq           : %.2f \n", packet.staticIaq);
  Serial.printf(" co2Equivalent       : %.2f \n", packet.co2Equivalent);
  Serial.printf(" breathVocEquivalent : %.2f \n", packet.breathVocEquivalent);
  Serial.printf(" co2                 : %.2f \n", packet.co2);
  Serial.printf(" pm2.5               : %.2f \n", packet.pm25);
  Serial.printf(" Sensor accuracy     : %d \n", packet.accuracy);
  Serial.println();
#endif

  server.update(macStr, &packet);
  digitalWrite(LED_BUILTIN, HIGH);
}

void setup() {
  pinMode(LED_BUILTIN, OUTPUT);
  Serial.begin(115200);
  Serial.println();
  Serial.println(F("-----------------------------------------------"));
  Serial.println(F("Healthy indoors project"));
  Serial.println(F("serial 2 homie mqtt broker"));
  Serial.println(F("version 0.0.1"));
  Serial.println(F("-----------------------------------------------"));

  // Init software serial
  Serial.println(F("initializing Serial Port on GPIO15 (D8) TX and GPIO13 (D7) RX"));
  Serial.print(F("Baud rate: "));
  Serial.println(BAUD_RATE);
  serialPort.begin(BAUD_RATE, D7, D8, SWSERIAL_8N1, false, 95, 11);
  
  // Init server
  server.init();
}
 
bool serialClean = false;

void loop() {
  // call server loop
  server.loop();

  // handle inputs on serial port
  if (serialPort.available() > 0) {
    if (!serialClean) {
      uint8_t serialInput = serialPort.read();
      Serial.print(serialInput);
      if (serialInput == 13 ) { // \r
        do {
          if (serialPort.available() > 0) {
            serialInput =  serialPort.read();
            Serial.print(serialInput);
          }
        } while (serialInput != 10); // \c
        Serial.println(F("end of package detected"));
        serialClean = true;
      }
    } else { // serial is "clean" so next package should be valid
      Serial.println();
      uint8_t packageLength = serialPort.read();
      serialBuffer[0]=packageLength;
      uint8_t payloadLength = packageLength; // length of payload
      packageLength+=HEADER_LENGTH; // add 6 for mac, 4 for checksum and 2 for \r\n
      // Serial.print(F("package start. Length: "));
      // Serial.println(packageLength);
      int count = 1;
      do {
        if (serialPort.available() > 0) {
          serialBuffer[count] = serialPort.read();
          count++;
          if (count >= SERIAL_BUFFER_MAX) {
            Serial.println(F("Buffer overflow! rescan"));
            serialClean = false;
            break;
          }
        }
      } while (count<packageLength+1);
      Serial.println();
      if (count == packageLength+1) {
        char macStr[18];
        Serial.print("Packet received from: ");
        snprintf(macStr, sizeof(macStr), "%02x:%02x:%02x:%02x:%02x:%02x",
           serialBuffer[1], serialBuffer[2], serialBuffer[3], serialBuffer[4], serialBuffer[5], serialBuffer[6]);
        Serial.print(macStr);
        Serial.print(F(" bytes="));
        Serial.print(payloadLength);
        Serial.print(F(" checksum: "));
        uint32_t checksumReceived =uint32_t((unsigned char)(serialBuffer[7+payloadLength]) |
            (unsigned char)(serialBuffer[8+payloadLength]) << 8 |
            (unsigned char)(serialBuffer[9+payloadLength]) << 16 |
            (unsigned char)(serialBuffer[10+payloadLength]) << 24);
        Serial.print(checksumReceived);
        checksum = CRC32::calculate(serialBuffer, payloadLength+7); // payload and 1 byte length & 6 byte MAC address
        Serial.print("(");
        Serial.print(payloadLength+7);
        Serial.print(")");
        Serial.print(F(":"));
        Serial.print(checksum);
        if (checksumReceived == checksum) {
          Serial.println(F(" ok"));
          OnDataRecv(&serialBuffer[1], &serialBuffer[7], packageLength - HEADER_LENGTH );
        } else {
          Serial.println(F(" missmatch!"));
          Serial.println();
          serialClean=false; // rescan for CR/LF
        }
      }
    }
  }
}
